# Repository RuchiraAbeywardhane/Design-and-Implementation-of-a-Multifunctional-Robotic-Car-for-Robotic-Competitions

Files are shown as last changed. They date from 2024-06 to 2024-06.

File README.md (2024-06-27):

# Agni Robot

* Agni is a robot powered by [Arduino Mega 2560](https://github.com/LasithaAmarasinghe/Agni-Robot/blob/main/Arduino%20Mega%202560%20Board.pdf), capable of doing various tasks in robotics competitions.
* This is developed for the semester 3 project under EN2533: Robot Design and Competition.
* The robot had to overcome several [tasks](https://github.com/LasithaAmarasinghe/Agni-Robot/blob/main/Robotics_Task.pdf) in this competition, which was held in an [arena](https://github.com/LasithaAmarasinghe/Agni-Robot/blob/main/Competition%20Arena.png) prepared in the ENTC building. 

IMG-20231209-WA00

## Functionalities

🛤️ Precise line following  
🚧 Wall avoidance during navigation  
🏞️ Navigating ramps (20 degrees)  
🤖 Object interaction with a mechanical arm  
🎵 Sound sensitivity   
🌈 Colour detection  
🌀 Maze-traversing capabilities  
🛑 Obstacle avoidance, including guard robots  

## Game Plan

### Task 1: Line Following
* For the initial task of the competition, the robot needs to follow the white line on the black background. To detect the line with better accuracy we used an IR array with 8 IR modules. For smoothing the movement of the robot we added a PID controller. The PID control processes the IR sensor data and makes real-time adjustments to the robot's motor output, ensuring that it stays on the line with precision.

### Task 2: Wall Following
* In this task, the white line is disturbed by walls at some points and the robot needs to follow the white line, avoiding the walls. To detect walls we used ultrasonic sensors. The robot manages to keep a constant distance from the walls in disturbed areas and comes back to the white line after that according to the algorithm.

### Task 3: Ramp Navigation
* To go through the ramp we focused on what needed to be done by the mechanical design side. We calculated the height that the chassis needs to be from the ground and where the tyres should be situated relative to the chassis. The PID controller is adjusted for this task to slow down the robot when it comes near the ramp, so the robot can smoothly enter the ramp.

### Task 4: Box Manipulation
* To tackle the box manipulation challenge, we added a robotic arm with stepper motors equipped with joints for precise movements. We used ultrasonic sensors to detect the presence of the box. After the box is detected, the arm grabs the box according to the code.

### Task 5: Coloured Line Following
* For this task, the robot needs to identify the colour of the box and follow the path with the same colour as the box. First, the box is picked up by the arm, and then using the colour sensor, the box's colour is detected. According to the colour of the box, the robot follows the line according to the right-hand rule to reach the destination.

### Task 6: Sound Detection
* In this part, there is a sound-emitting tower. The robot should freeze when a sound is emitted from the tower and should move only when it's silent. With the sound sensor, the robot detects the sound and moves according to the algorithm. 

### Task 7: Guard Bot Avoidance
* In the final task, the robot encounters a guard robot blocking its path. Ultrasound sensors are strategically positioned on the front sides of the robot to detect the movements of the guard bot. When the bot moves away from our destination, our robot successfully evades the guard robot and reaches the final destination.

## Hardware Specifications

* [Arduino Mega 2560](https://github.com/LasithaAmarasinghe/Agni-Robot/blob/main/Arduino%20Mega%202560%20Board.pdf)
* [Sensors](https://github.com/LasithaAmarasinghe/Agni-Robot/blob/main/AGNI%20sensors%20.pdf)
* Buck Converter
* 2 Li-ion Batteries
* 2 N20 50 rpm Motors
* Wheels

## Software Specifications

* Arduino IDE
* Solid Works




## Sensors



## Chassie Design

Bottom Chassie

## Team


<p align="center">
  Image Description
</p>

## License
 
 * This project is licensed under the MIT License. See the [LICENSE](MIT-LICENSE.txt) file for details.

## For More Information - [Project Report](https://github.com/LasithaAmarasinghe/Agni-Robot/blob/main/Agni%20final%20report.pdf)

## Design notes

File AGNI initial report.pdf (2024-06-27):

### EN2533 Robot Design and Competition Team AGNI Overview

Overall Strategy

Line Following:
We will use 10 analog IR sensors to detect the white colour line. These sensors provide analog values, and by setting a threshold value these values can be converted into digital values. Then the PID algorithm, which is implemented in a microcontroller, will set the speed of each motor.

Wall Following:
We will use two TOF sensors to both sides of the robot. According to their input, the distance of the obstacle will be calculated and motor speed will be changed. It is important to note that for this task we will give priority to obstacle avoidance over line following.

Bridge:
Throughout this task, the line following method will be used. If we find a small door open box, the arm will grab the box, then the robot will move backward until it reaches the junction. then it turns right and moves forward until it reaches checkpoint 4 again.

Colour line:
Firstly, to detect the colour of the box we will use an RGB colour sensor. Then we will use 10 IR sensors which are already used for line following. But for this task we will change the threshold values for red and blue. We are also going to use the PID algorithm, but here we will use a search method to reach checkpoint 6.

Mechanical Design

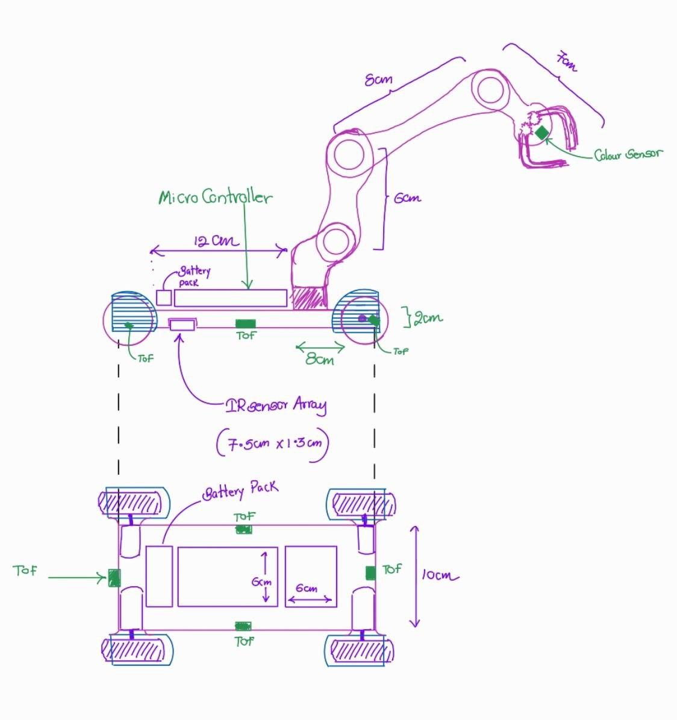
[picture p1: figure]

Sensors

Obstacle Detection & Guard Bot part: Selected Sensor: TOF VL6180V1 Proximity Sensor
Reasons for Selection:
- High accuracy in measuring distances
- Unaffected by ambient light
- Small physical size for flexible integration
- Extended range from 0 to 60cm

Line Following:
Selected Sensor: IR Array
Reasons for Selection:
- Provides wider coverage area for efficient line following
- Simplifies sensor setup with multiple IR sensors in one package

Colour Detection:
Selected Sensor: TCS230 Color Sensor Reasons for Selection:
- High accuracy in colour detection

- Versatile in distinguishing a wide range of colours

Sound Detection:
Selected Sensor: MD0220 Voice Sound Detection Mic Sensor
Reasons for Selection:
- Designed specifically for voice and sound detection
- Optimised for voice detection, suitable for reacting to voice commands or environmental
sounds

Actuators

We plan to use two N20 motors for rear wheels.
Options - N20 motors, plastic motors Reasons for Selection:
- higher efficiency
- low power consumption,
- It has the required rpm value to carry the robot on the ramp. Algorithms

Line Following
get input from IR and A2D Conversion calculate Speed using PID (Proportional integral derivative Algorithm)
set speed

Obstacle Detection
get input from TOF sensor
calculate distance (D)
if D <2cm
set new speed according the TOF sensor side

Red/Blue Line Following
get input from IR and A2D Conversion if all (IR) = 0
turn 180°
forward

until All (IR) != 0
else
calculate speed using PID [Priority Left, Forward, Right]
set speed

Box Detection
get TOF input [ Front TOF] calculate distance
forward until distance = d cm //d will be determined

Sound Detection
get input from sound sensor if input = 1
follow line
else
break

Guard Bot
get input from TOF sensors
if right TOF detects before left TOF turn right
forward
until find checkpoint 8
else
wait
Task Delegation
- Thamirawaran - Line following, obstacle avoiding
- Ruchira Abeywardane -PCB design, arm coding part.
- Lasitha Amarasinghe -Guard bot part, Adjust the overall code for task wise functioning
- Rajitha Niroshan -Solidwork design, Ramp Task
- Sahan Abeyrathna -Colour detection and sound detection part

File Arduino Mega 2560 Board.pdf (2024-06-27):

Arduino Mega 2560 Board

The Arduino Mega 2560 is a microcontroller board designed for more complex projects that require a greater number of input and output (I/O) pins, larger sketch memory, and more RAM. It’s easier to work with arduino Mega 2560 thanks to its 54 digital I/O pins, 16 analog inputs and larger space . It is a more advanced version of the traditional Arduino boards with a wide range of subsystems to enable different functionalities.

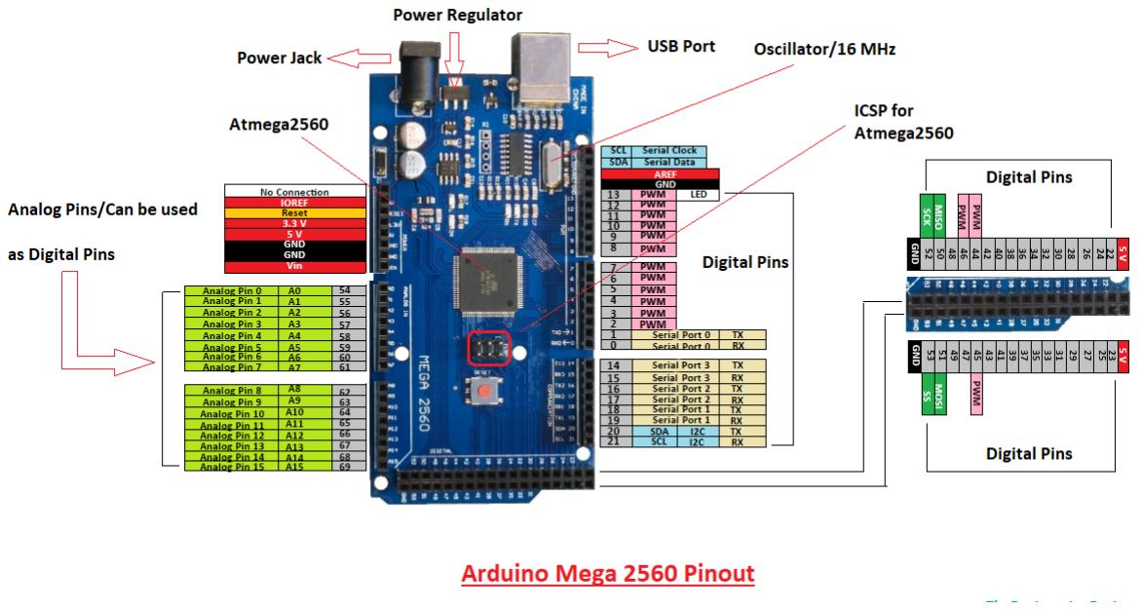
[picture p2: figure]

1. Microcontroller Unit (MCU):
- This is an 8-bit AVR microcontroller.
- The MCU is responsible for executing the programs, handling digital and analog input/output, and controlling various sensors and actuators.
- It has built-in Flash memory for program storage, SRAM for variable storage, and EEPROM for data storage.
2. 54 Digital I/O Pins:
- The Arduino Mega 2560 offers 54 digital I/O pins. These pins can be used for digital input or output operations.
- Each digital I/O pin is connected to the MCU, allowing to control external devices, such as LEDs, motors, and relays.
3. 16 Analog Input Pins:
- The board provides 16 analog input pins, which can be used to read analog signals from sensors.
- The analog-to-digital converter (ADC) subsystem within the MCU converts these analog signals into digital values for use in the sketch.

4. Crystal Oscillator:
- The MCU typically uses a crystal oscillator to provides exceptional frequency accuracy and stability.
- The Arduino Mega 2560 uses a 16 MHz crystal oscillator.
5. Voltage Regulator:
- This provides a stable 5V supply from the external power source (usually 7-12V DC).
- This ensures that the MCU and other components receive a consistent and regulated voltage.
6. USB Interface:
- USB-to-Serial converter allows to connect the Arduino to a computer for programming and communication.
- It also powers the board and can be used for serial communication between the board and the computer.
7. Power Supply Connectors:
- There are multiple power supply connectors, such as the barrel jack and Vin pin, for providing power to the board from external sources.
- Can choose between the USB power source and an external power supply, depending on application.
8. Reset Button:
- This allows to reset the microcontroller, which is useful for restarting the sketch or entering the bootloader for programming.
9. Communication Interfaces:
- Arduino Mega 2560 has multiple communication interfaces, including UART (Serial), SPI, and I2C, which allow to communicate with other devices and sensors.
10. LEDs:
- LEDs are often used for debugging and status monitoring.

These subsystems and components work together to make the Arduino Mega 2560 a versatile and powerful development platform for a wide range of projects.

Resourceshttps://store.arduino.cc/products/arduino-mega-2560-rev3https://www.theengineeringprojects.com/2018/06/introduction-to-arduino-mega -2560.html (https://www.theengineeringprojects.com/2018/06/introduction-to-arduino-mega-2560.html)

Lasitha Amarasinghe - 210031H - Agni

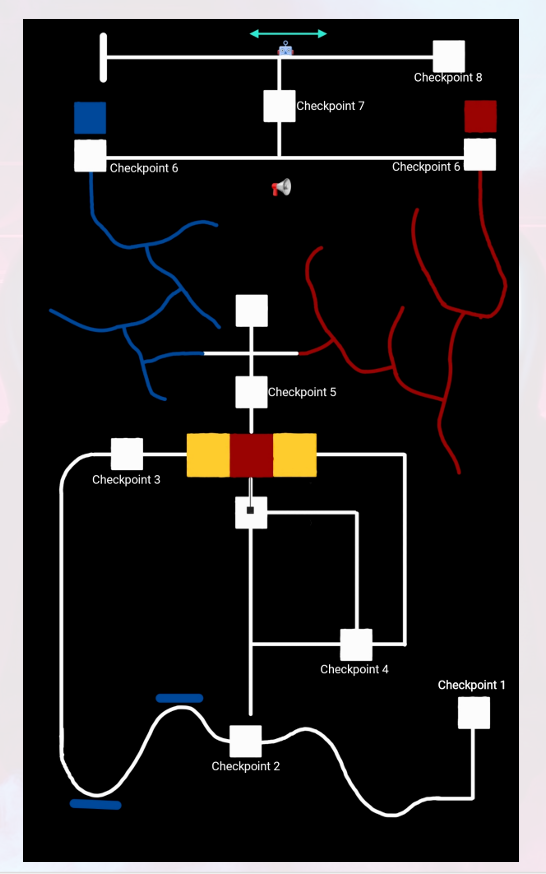
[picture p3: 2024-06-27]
Competition Arena.png

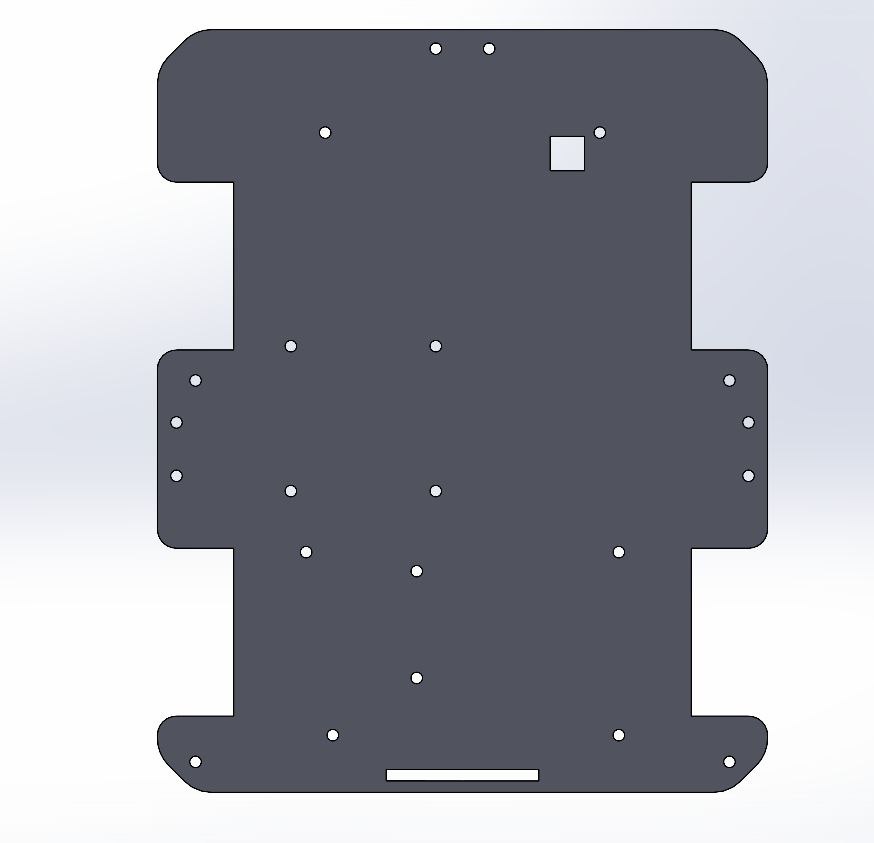
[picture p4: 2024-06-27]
Solid works/bottom chassie.jpg

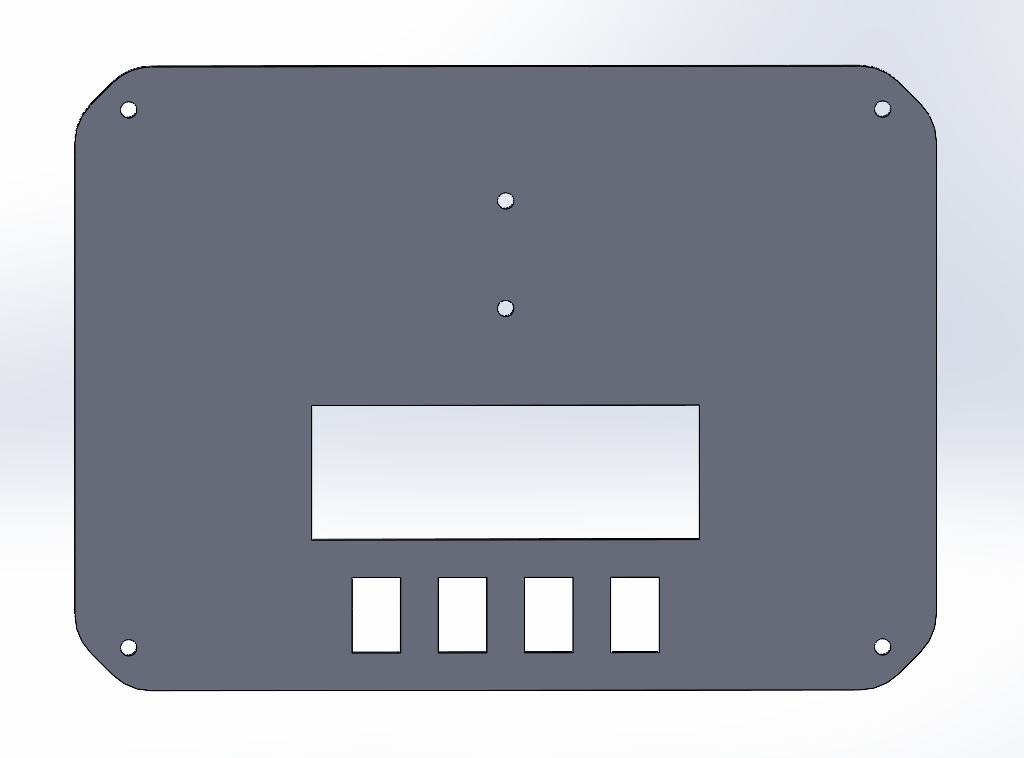
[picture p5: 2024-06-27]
Solid works/top chassie.jpg

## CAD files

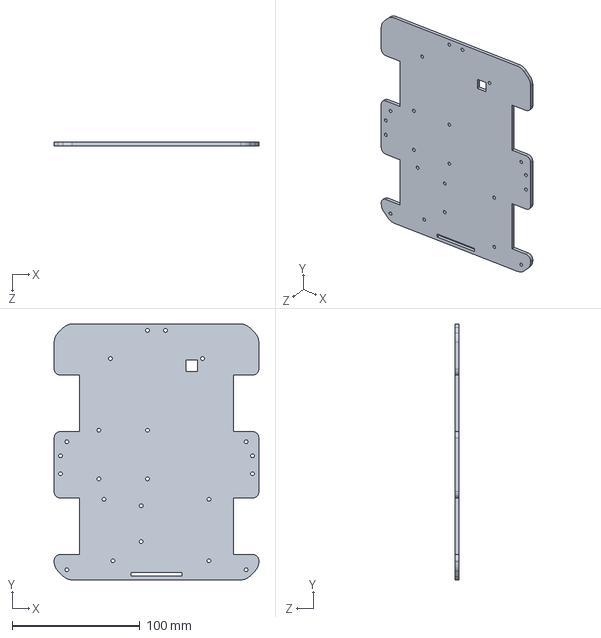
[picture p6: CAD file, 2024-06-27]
Solid works/chassie_1.SLDPRT
160.0 x 200.0 x 3.00 mm

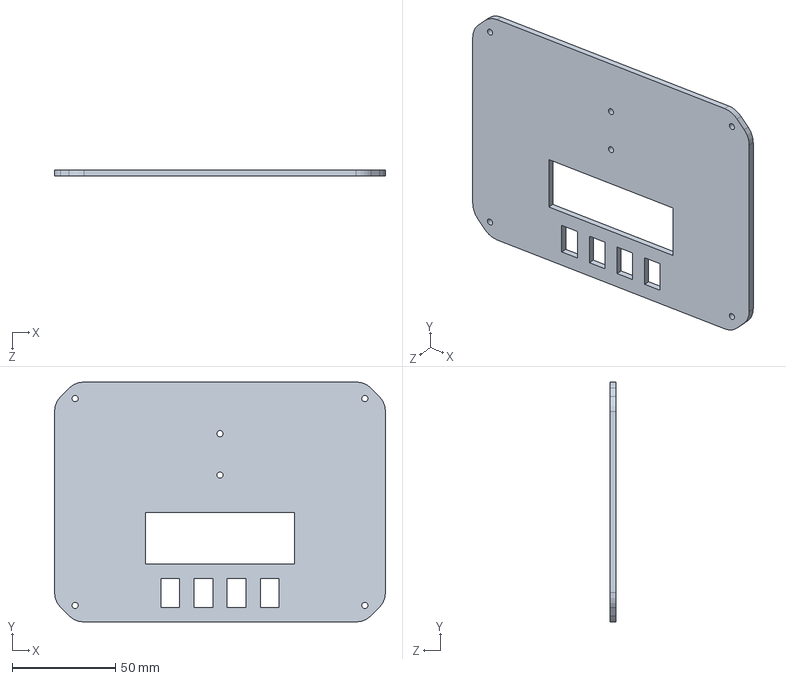
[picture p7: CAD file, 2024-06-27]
Solid works/chassie_2.SLDPRT
160.0 x 116.0 x 3.00 mm

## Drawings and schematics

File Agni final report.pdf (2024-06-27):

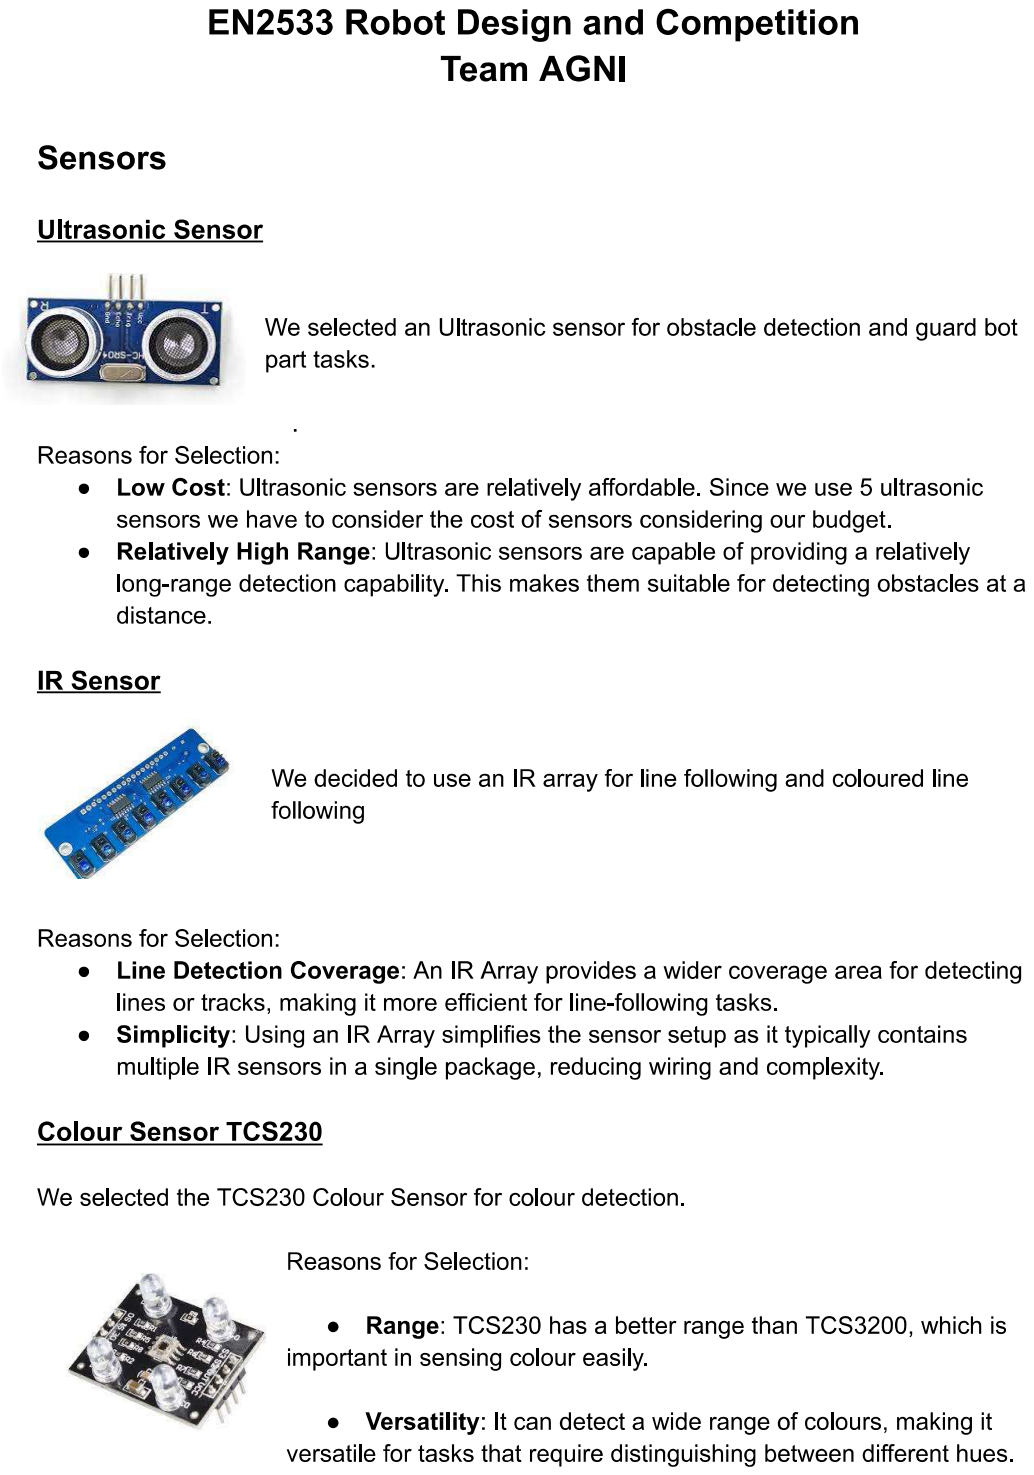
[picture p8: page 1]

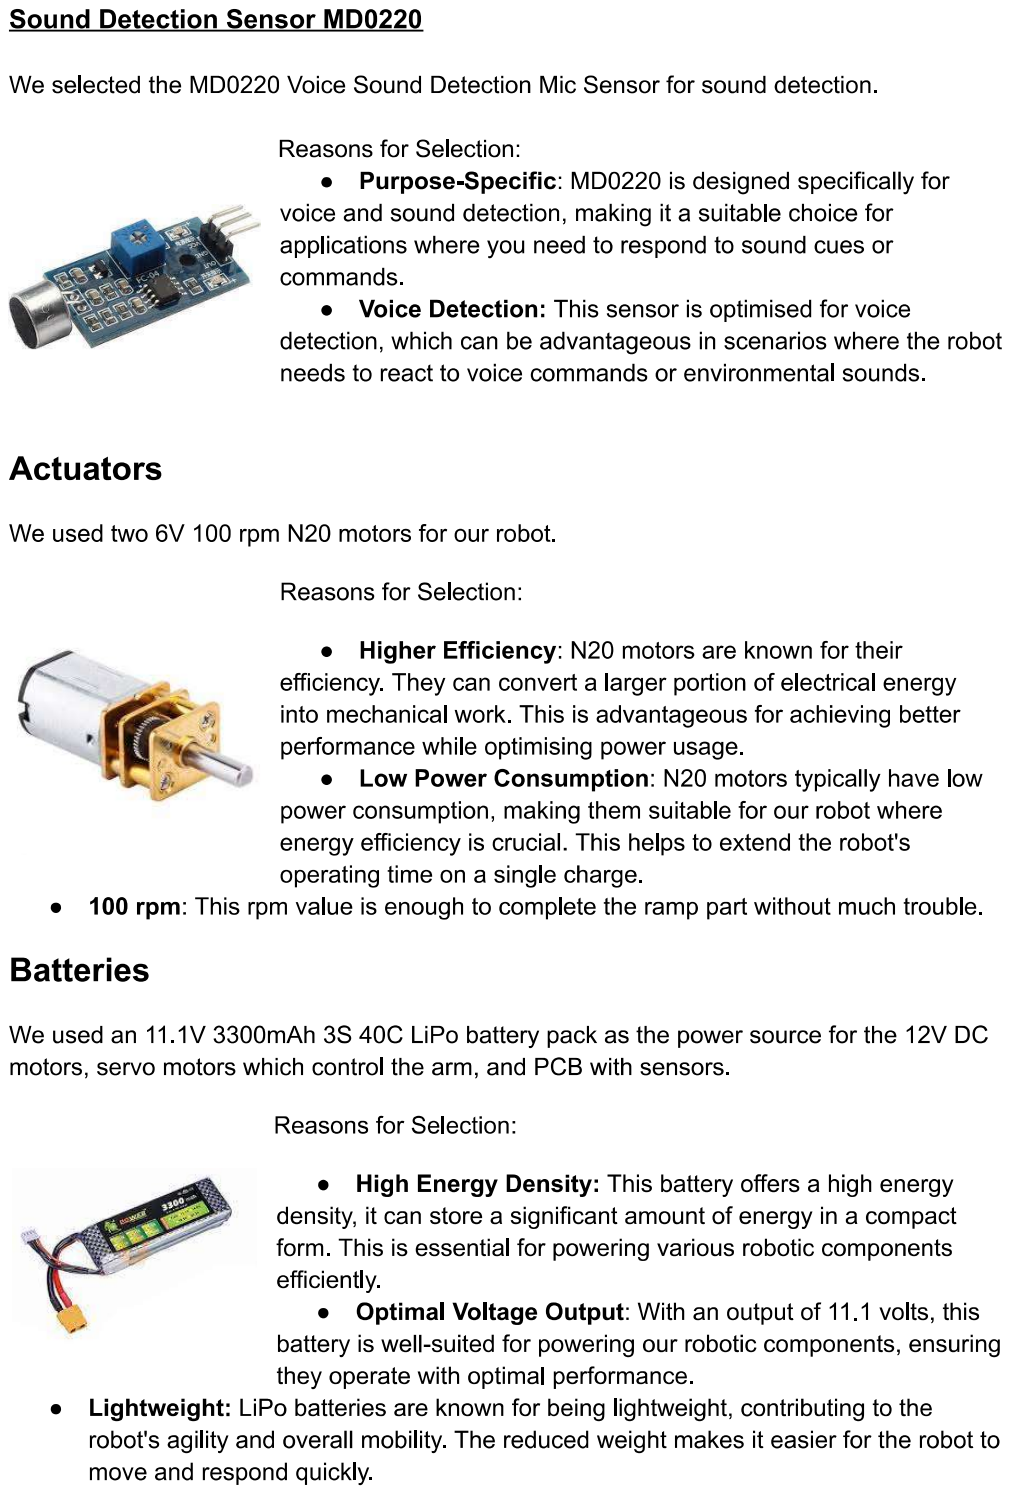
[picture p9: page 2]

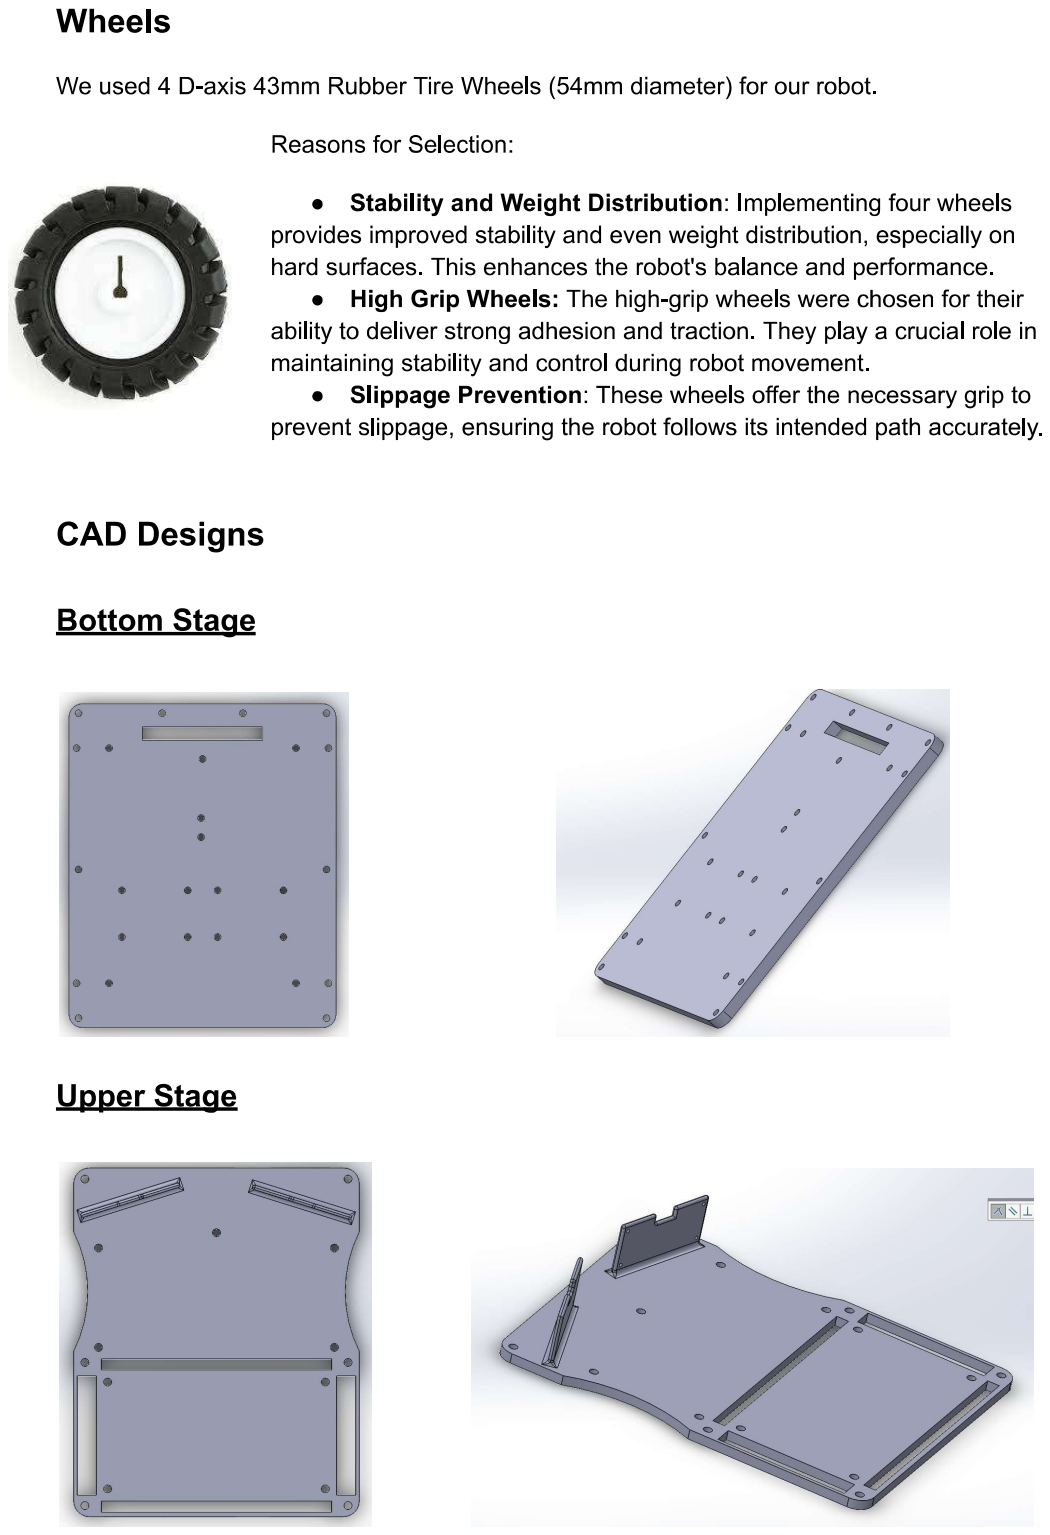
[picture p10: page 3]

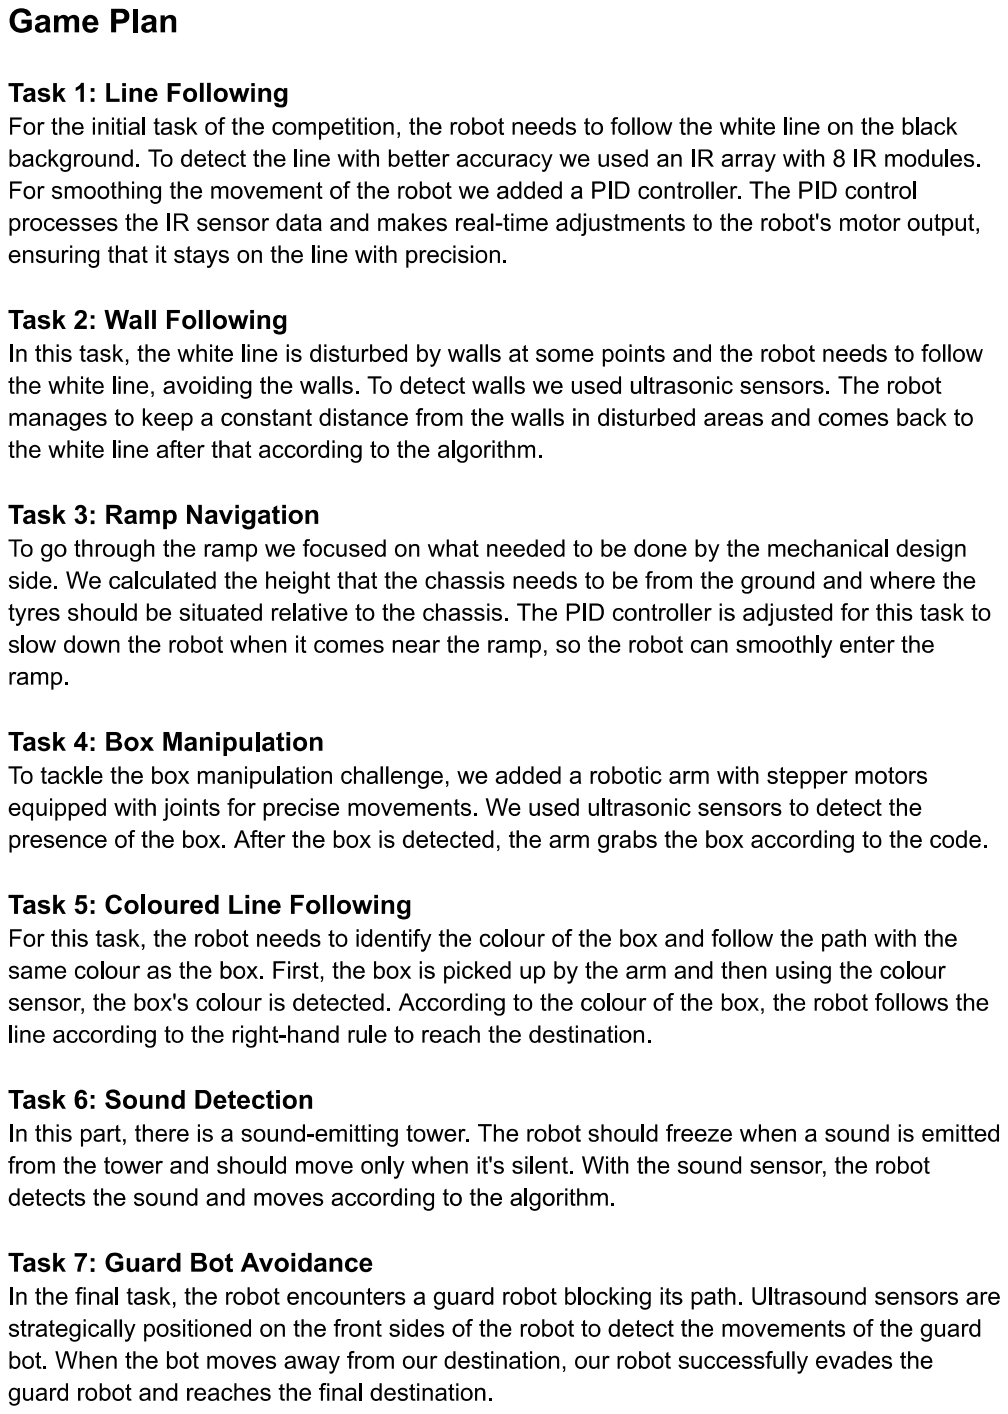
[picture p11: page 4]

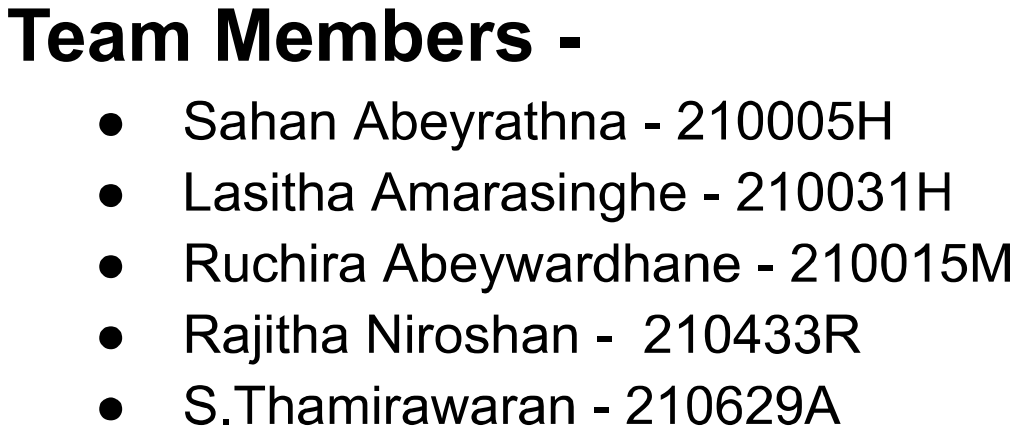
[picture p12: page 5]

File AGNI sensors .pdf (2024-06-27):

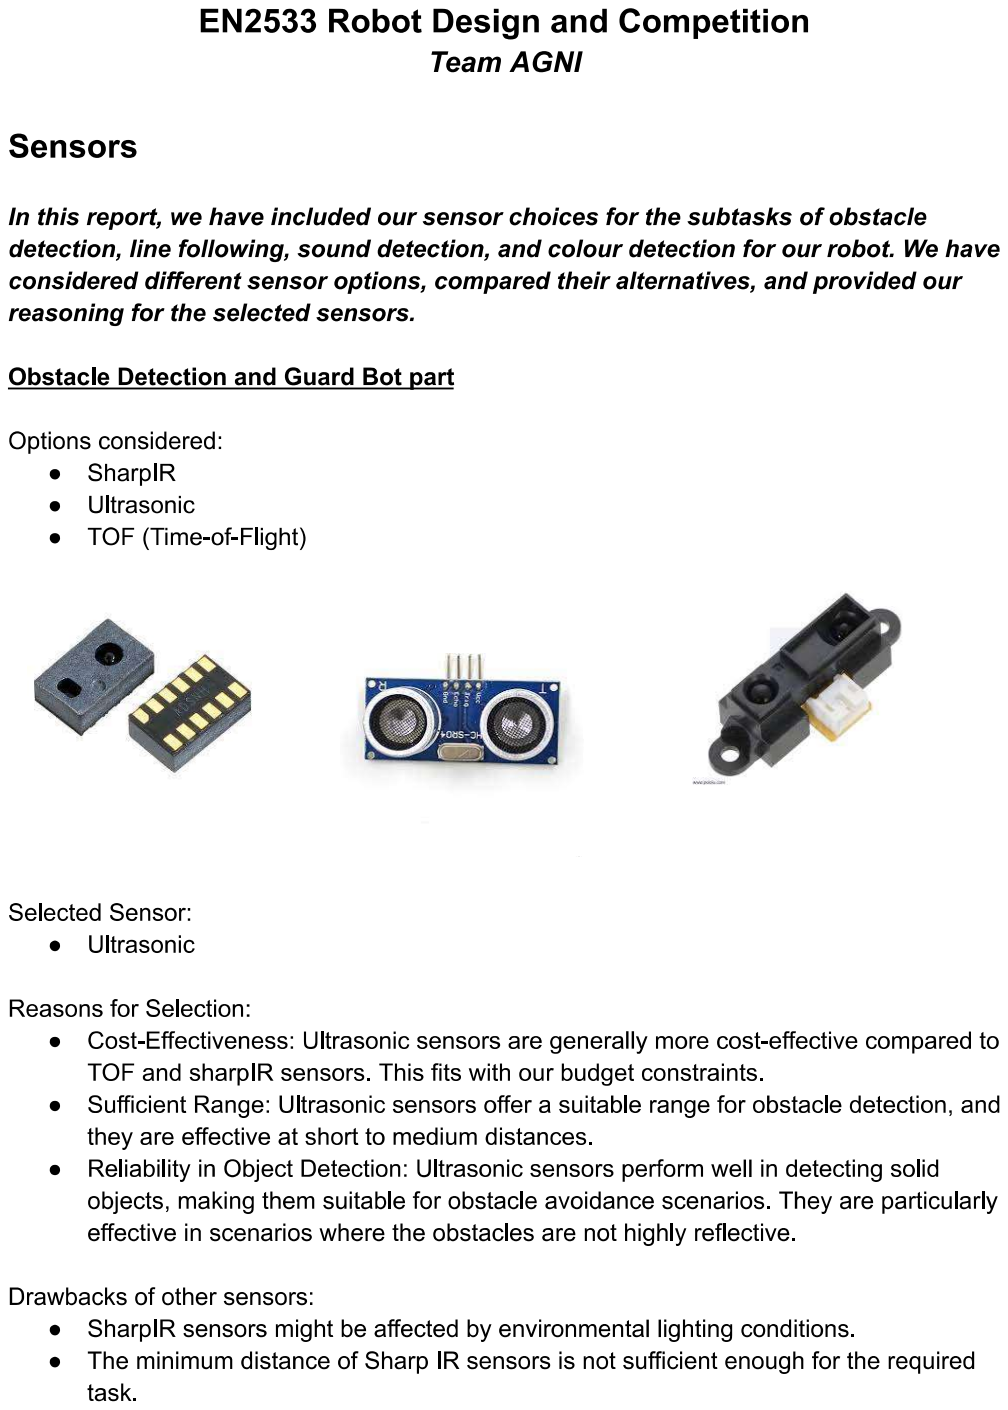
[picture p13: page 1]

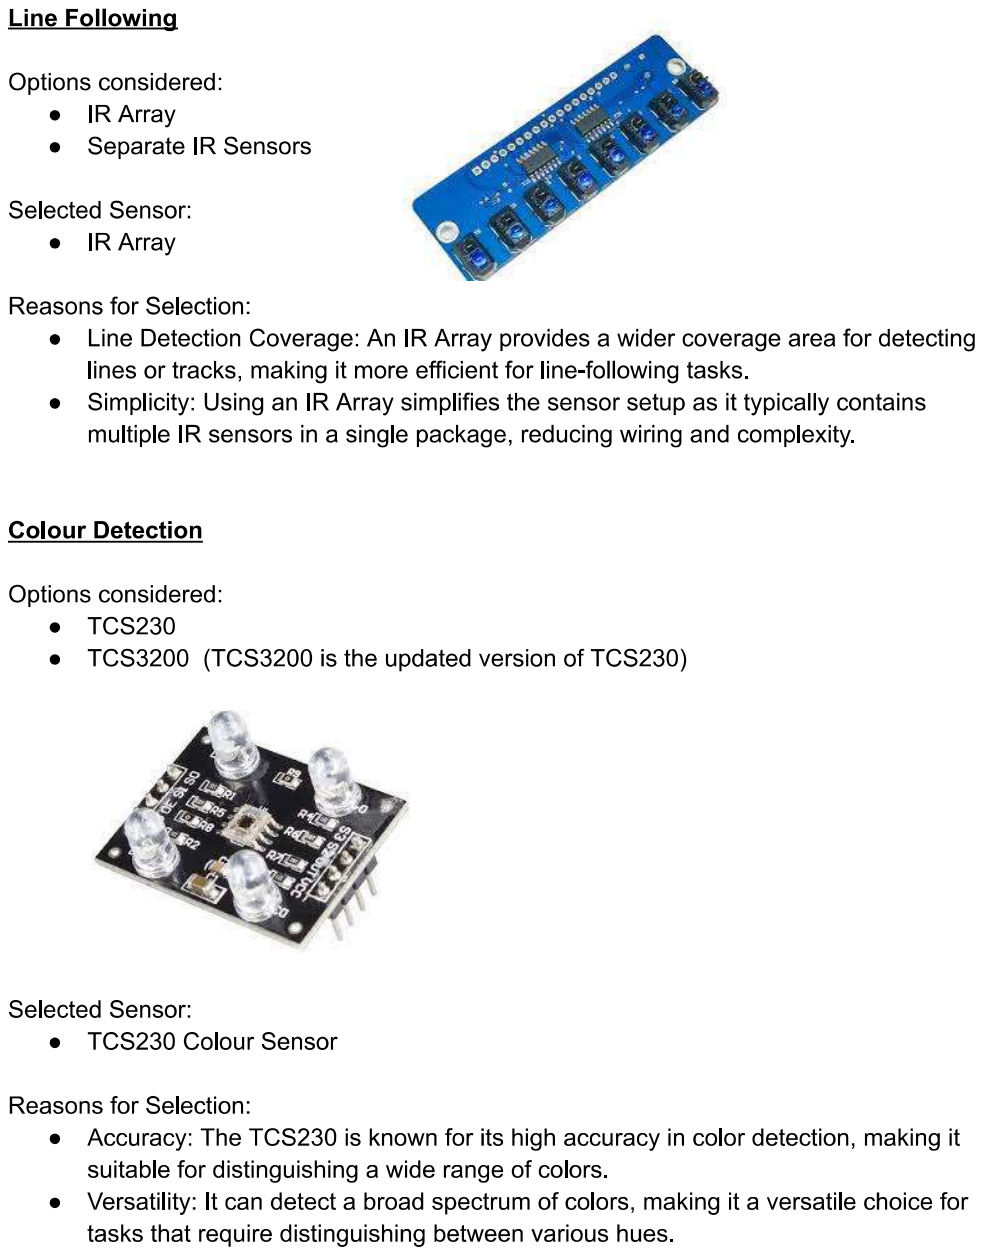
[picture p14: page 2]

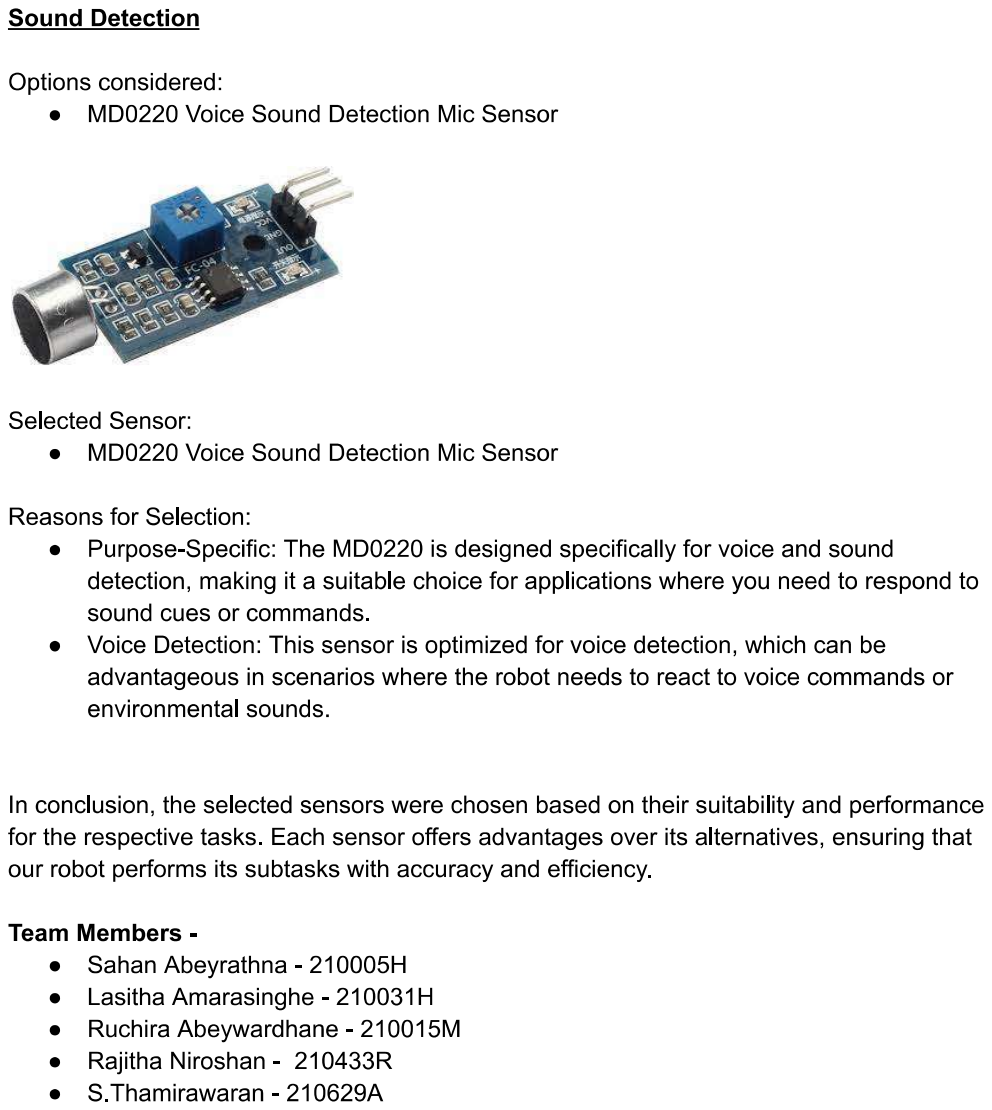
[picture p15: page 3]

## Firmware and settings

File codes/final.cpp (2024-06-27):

#include <Arduino.h>
#include <Wire.h>
#include <Servo.h>
#include <NewPing.h>


#define IR1 A0
#define IR2 A1
#define IR3 A2
#define IR4 A3
#define IR5 A4
#define IR6 A5
#define IR7 A6
#define IR8 A7

#define RMotorA 4
#define RMotorB 2
#define RMotorPWM 3

#define LMotorA 7
#define LMotorB 6
#define LMotorPWM 5

#define S0 A9
#define S1 A10
#define S2 A15
#define S3 A14
#define sensorOut A12
#define colourVcc A13
#define colourGnd A11

#define sensor A14 // Sharp IR GP2Y0A41SK0F (4-30cm, analog)

#define HighSwitch 36
#define RightSwitch 34
#define MiddleSwitch 32
#define LeftSwitch 30

#define MAX_DISTANCE 20 // Maximum distance we want to ping for (in centimeters). Maximum sensor distance is rated at 400-500cm.


// Stores frequency read by the photodiodes
int red = 0;
int green = 0;
int blue = 0;


// Define pins for the  sensor-Front left sensor
const int trigPin_FL = 45;
const int echoPin_FL = 47;
const int gndPin_FL = 49;

// Define pins for the sensor-left
const int trigPin_L = 51;
const int echoPin_L = 53;

// Define pins for the third sensor-middle sensor
const int trigPin_M = 39;
const int echoPin_M = 41;
const int gndPin_M = 43;


// Define pins for the fourth sensor-right  sensor
const int trigPin_R = 36;
const int echoPin_R = 38;
const int gndPin_R = 40;

// Define pins for the fifth sensor-right front sensor
const int trigPin_FR = 46;
const int echoPin_FR = 48;
const int gndPin_FR = 52;


//Ground sharpir
const int sharpGND = 22;

// Declare the Servo pin
int servoPin1 = 9;
int servoPin2 = 8;

// Declare distances to walls
int ultradist = 0;
int ultradist1 = 0;
int ultradist2 = 0;
int ultradist3 = 0;
int ultradist4 = 0;
int ultradist5 = 0;

int start = 0;

int BaseSpeed = 80;
int MinSpeed = 0;
int MaxSpeed = 160;

int IR_D_val[8] = {0, 0, 0, 0, 0, 0, 0, 0};
int Temp_IR_D_val[8];
int IR_A_val[8] = {0, 0, 0, 0, 0, 0, 0, 0};
//int IR_Weight[8]= {-20, -10, -5, 0 , 0 , 5, 10, 20};
int IR_Weight[8] = { -35, -20, -10, -5 , 5 , 10, 20, 35};

int LMotorSpeed = 0;
int RMotorSpeed = 0;
int SpeedAdjust = 0;

float P, I, D;
float Error = 0;
float PreviousError = 0;
float Kp = 10; //2.8
float Kd = 0;
float Ki = 0;

void PID_control();
void read_IR();
void set_speed();
void set_forward();

//Calibeartion Arrays
const int Buzzer = 51;
const int BuzzerGND = 44;
int caliberation_threshold[8];

// Create a servo object
Servo Servo1; //servo which controls rotation of arm
Servo Servo2; //servo which controls gripper part

int stage = 2;

const int soundSensorPin = A1;

void setup() {
  Serial.begin(9600);


  // Setting colour sensor outputs
  pinMode(S0, OUTPUT);
  pinMode(S1, OUTPUT);
  pinMode(S2, OUTPUT);
  pinMode(S3, OUTPUT);
  pinMode(sensorOut, INPUT);  // Setting the sensorOut as an input
  digitalWrite(S0, HIGH);     // Setting frequency scaling to 20%
  digitalWrite(S1, LOW);
  digitalWrite(colourVcc, HIGH);
  digitalWrite(colourGnd, LOW);

  // Set up pins for ultrasonic sensors
  pinMode(trigPin_FL, OUTPUT);
  pinMode(echoPin_FL, INPUT);
  pinMode(trigPin_L, OUTPUT);
  pinMode(echoPin_L, INPUT);
  pinMode(trigPin_M, OUTPUT);
  pinMode(echoPin_M, INPUT);
  pinMode(trigPin_R, OUTPUT);
  pinMode(echoPin_R, INPUT);
  pinMode(trigPin_FR, OUTPUT);
  pinMode(echoPin_FR, INPUT);

  //sharpir pins
  pinMode(sharpGND, OUTPUT);
  pinMode(sharpIR, INPUT);
  digitalWrite(sharpGND, LOW);


  //Defining Pin modes for the Buzzer(Caliberation)
  pinMode(Buzzer, OUTPUT);
  pinMode(BuzzerGND, OUTPUT);
  digitalWrite(Buzzer, LOW);
  digitalWrite(Buzzer, LOW);

  pinMode(IR1, INPUT);
  pinMode(IR2, INPUT);
  pinMode(IR3, INPUT);
  pinMode(IR4, INPUT);
  pinMode(IR5, INPUT);
  pinMode(IR6, INPUT);
  pinMode(IR7, INPUT);
  pinMode(IR8, INPUT);

  pinMode(RMotorA, OUTPUT);
  pinMode(RMotorB, OUTPUT);
  pinMode(RMotorPWM, OUTPUT);

  pinMode(LMotorA, OUTPUT);
  pinMode(LMotorB, OUTPUT);
  pinMode(LMotorPWM, OUTPUT);

  Servo1.attach(servoPin1);
  Servo2.attach(servoPin2);

  set_forward();
  Servo1.write(70);
  Servo2.write(90);
  delay(500);


//ultrasonic grounds
  digitalWrite(gndPin_FR, LOW);
  //  digitalWrite(gndPin2, LOW);
  digitalWrite(gndPin_R, LOW);
  digitalWrite(gndPin_M, LOW);
  digitalWrite(gndPin_FL, LOW);

}

/////////////////Direction///////////////////////////
int turnTo(int dataset[]) { //Determine where to turn to lose the deviation
  int sumRight = 0;
  int sumLeft = 0;
  for (int i = 0; i < 4; i++) {
    sumRight += dataset[i];
    sumLeft += dataset[i + 4];
  }
  if (sumRight > sumLeft) {
    return 1; //1 means turn right, if the vehicle is turning wrong change this to 0
  }
  else {
    return 0; //0 means Turn Left
  }
}
//////////////////////////////////////////////////////


/////////////////Deviator///////////////////////////
int deviator(int dataset[]) { ///Check if the robot has deviated from the line
  if (dataset[0] == 1 && dataset[1] == 1 && dataset[2] == 1 && dataset[3] == 1 && dataset[4] == 1 && dataset[5] == 1 && dataset[6] == 1 && dataset[7] == 1 ) {
    return 1;
  }
  else {
    return 0;
  }
}
//////////////////////////////////////////////////////


/////////////////Checkpoint///////////////////////////
int checkpoint(int dataset[]) { ///Check if the robot has reached a checkpoint
  if (dataset[0] == 0 && dataset[1] == 0 && dataset[2] == 0 && dataset[3] == 0 && dataset[4] == 0 && dataset[5] == 0 && dataset[6] == 0 && dataset[7] == 0 ) {
    return 1;
  }
  else {
    return 0;
  }
}
//////////////////////////////////////////////////////
void PID_control() {
  Error = 0;
  for (int i = 0; i < 8; i++) {
    Error += IR_Weight[i] * IR_D_val[i];
  }
  P = Error;
  I = I + Error;
  D = Error - PreviousError;
  PreviousError = Error;

  SpeedAdjust = (Kp * P + Ki * I + Kd * D);

  LMotorSpeed = BaseSpeed - SpeedAdjust;
  RMotorSpeed = BaseSpeed + SpeedAdjust;
  // delay(5000);

  if (LMotorSpeed < 0 ) {
    LMotorSpeed = 0;
  }
  if (RMotorSpeed < 0) {
    RMotorSpeed = 0;
  }
  if (LMotorSpeed > MaxSpeed) {
    LMotorSpeed = MaxSpeed;
  }
  if (RMotorSpeed > MaxSpeed) {
    RMotorSpeed = MaxSpeed;
  }

}
void stage5(){
  /*if (ultradist1<8){
    stop();
  }*/
    //Colour sensor 
    
    // Setting RED (R) filtered photodiodes to be read
    digitalWrite(S2,LOW);
    digitalWrite(S3,LOW);
    red = pulseIn(sensorOut, LOW);
    Serial.println("R:");
    Serial.println(red);
    
    // Setting GREEN (G) filtered photodiodes to be read
    digitalWrite(S2,HIGH);
    digitalWrite(S3,HIGH);
    green = pulseIn(sensorOut, LOW);
    Serial.println("G:");
    Serial.println(green);
    
    // Setting BLUE (B) filtered photodiodes to be read
    digitalWrite(S2,LOW);
    digitalWrite(S3,HIGH);
    blue = pulseIn(sensorOut, LOW);
    Serial.println("B:");
    Serial.println(blue);
    
    if (red>blue){
      Serial.println('red');
      }
    else if (red<blue){
      Serial.println('blue');
    }        
  }
void read_IR() {
  IR_A_val[0] = analogRead(IR1);
  IR_A_val[1] = analogRead(IR2);
  IR_A_val[2] = analogRead(IR3);
  IR_A_val[3] = analogRead(IR4);
  IR_A_val[4] = analogRead(IR5);
  IR_A_val[5] = analogRead(IR6);
  IR_A_val[6] = analogRead(IR7);
  IR_A_val[7] = analogRead(IR8);

  for (int i = 0; i < 8; i++)
  {
    if (IR_A_val[i] <= 300) {  //IR_A_val[i] >= caliberation_threshold[i] For Black Line
      IR_D_val[i] = 0;
    }
    else if (IR_A_val[i] >= 300) {
      IR_D_val[i] = 1;
    }
  }
}


void set_speed() {
  analogWrite(LMotorPWM, LMotorSpeed);
  analogWrite(RMotorPWM, RMotorSpeed);
}

void set_forward() {
  digitalWrite(LMotorB, HIGH);
  digitalWrite(LMotorA, LOW);
  digitalWrite(RMotorB, HIGH);
  digitalWrite(RMotorA, LOW);
}

void TurnRight() {
  analogWrite(LMotorPWM, 100);
  analogWrite(RMotorPWM, 100);
  digitalWrite(LMotorB, HIGH);
  digitalWrite(LMotorA, LOW);
  digitalWrite(RMotorB, LOW);
  digitalWrite(RMotorA, HIGH);
}


void TurnLeft() {
  analogWrite(LMotorPWM, 100);
  analogWrite(RMotorPWM, 100);
  digitalWrite(LMotorB, LOW);
  digitalWrite(LMotorA, HIGH);
  digitalWrite(RMotorB, HIGH);
  digitalWrite(RMotorA, LOW);
}

void stop() {
  digitalWrite(LMotorB, LOW);
  digitalWrite(LMotorA, LOW);
  digitalWrite(RMotorB, LOW);
  digitalWrite(RMotorA, LOW);
}


/////////////////////Caliberation//////////////////////
void caliberation() {
  int caliberation_data[8][12] = {
    {}, // Inner array 1
    {}, // Inner array 2
    {}, // Inner array 3
    {}, // Inner array 4
    {}, // Inner array 5
    {}, // Inner array 6
    {}, // Inner array 7
    {}  // Inner array 8
  };
  delay(2000);
  digitalWrite(Buzzer, HIGH);
  delay(100);
  digitalWrite(Buzzer, LOW);
  delay(3000);

  int n = 0;
  for (int i = 0; i < 12; i++) {
    Serial.println(n);
    for (int j = 0; j < 8; j++) {
      caliberation_data[j][i] = analogRead(IR_A_val[j]); //j value represents the IR single modules i represents the number of times values are taken
    }
    if (n == 2) {
      //Go forward few steps
      analogWrite(LMotorPWM, 255);
      analogWrite(RMotorPWM, 255);
      set_forward();
      delay(500);
      stop();
    }
    else if (n == 5) {
      //Double beep to notify to move the car
      digitalWrite(Buzzer, HIGH);
      delay(100);
      digitalWrite(Buzzer, LOW);
      delay(100);
      digitalWrite(Buzzer, HIGH);
      delay(100);
      digitalWrite(Buzzer, LOW);
      delay(4000);
    }
    else if (n == 8) {
      //Go forward few steps
      analogWrite(LMotorPWM, 255);
      analogWrite(RMotorPWM, 255);
      set_forward();
      delay(500);
      stop();
    }
    else if (n == 11) {
      digitalWrite(Buzzer, HIGH);
      delay(100);
      digitalWrite(Buzzer, LOW);
      delay(100);
      digitalWrite(Buzzer, HIGH);
      delay(100);
      digitalWrite(Buzzer, LOW);
      delay(100);
      digitalWrite(Buzzer, HIGH);
      delay(100);
      digitalWrite(Buzzer, LOW);
      delay(4000);
      //End
    }
    n = n + 1;
  }

  for (int j = 0; j < 8 ; j++) {
    int maxi = 0;
    int mini = 0;
    for (int i = 0; i < 12; i++) {
      if (caliberation_data[j][i] > maxi) {
        maxi = caliberation_data[j][i];
      }
      else if (caliberation_data[j][i] < mini) {
        mini = caliberation_data[j][i];
      }
    }
    int avg = (maxi + mini) / 2;
    caliberation_threshold[j] = avg;
  }
}
///////////////////////////////////////////////////////
///////////////////GetBackTothePath///////////////////
void getBackPath(int hasDeviate) {
  //direction
  int turningTo = turnTo(Temp_IR_D_val);
  if (turningTo == 0) {
    ////turnleft
    ///when black detected
    delay(250);
    while (hasDeviate == 1) {
      TurnLeft();
      read_IR();
      hasDeviate = deviator(IR_D_val);
    }

  }
  else {
    //turn right
    ///when black detected
    delay(250);
    while (hasDeviate == 1) {
      TurnRight();
      read_IR();
      hasDeviate = deviator(IR_D_val);
    }

  }
}

/////////////////GetDistance///////////////////////
float getDistance(int trigPin, int echoPin) {
  NewPing sonar(trigPin, echoPin, MAX_DISTANCE); // NewPing setup of pins and maximum distance.
  float distance;
  delay(50);
  distance = sonar.ping_cm(); // Wait 50ms between pings (about 20 pings/sec). 29ms should be the shortest delay between pings.
  return distance;
}

////////////////////////////////////////////////////
////////////////////LineFollow//////////////////////
void LineFollow() {
  set_forward();
  PID_control();
  set_speed();
  for (int i = 0; i < 8; i++) {
    Temp_IR_D_val[i] = IR_D_val[i];
  }
}
/////////////////////////////////////////
/////////////////sharpIR////////////////
// 5v
float sharpIR() {
  float volts = analogRead(sensor) * 0.0048828125; // value from sensor * (5/1024)
  int distance = 13 * pow(volts, -1); // worked out from datasheet graph
  delay(10); // slow down serial port

  if (distance <= 30) {
    Serial.println(distance);   // print the distance
  }
}
//////////////////////////

void loop() {
  //////Caliberate at the start
  //if (start == 0) {
  //  caliberation();
  //  start += 1;
  //}
  read_IR(); //Read from IR sensor Array
  stage5();


////Detect Checkpoints///
  if (checkpoint(IR_D_val)) {
    delay(200);
    //read_IR();
    stop();
  }
  else { //Car is not at a checkpoint


    if (stage == 1) {
      Serial.println("Stage01");
      int hasDeviate = deviator(IR_D_val);
      if (hasDeviate == 1) {
        getBackPath(hasDeviate);
      }///////End of Has Deviate If statement
      else {
        LineFollow();
      }
    }//////End of Stage01



    else if (stage == 2) {
      /////Stage02
      LineFollow();
      Serial.println("*************************");
      Serial.print("front left");
      Serial.println(getDistance(trigPin_FL, echoPin_FL));
      Serial.print("left");
      Serial.println(getDistance(trigPin_L, echoPin_L));
      Serial.print("mid");
      Serial.println(getDistance(trigPin_M, echoPin_M));
      Serial.print("right");
      Serial.println(getDistance(trigPin_R, echoPin_R));
      Serial.print("front right");
      sharpIR();
      Serial.println("*************************");
      delay(2000);
    }
  }
}

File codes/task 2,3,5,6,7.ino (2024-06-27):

#include <Arduino.h>
#include <Wire.h>
#include <Adafruit_TCS34725.h>

const int IR_array[] = {A0, A1, A2, A3, A4, A5, A6, A7};  //A0-RightMost
Adafruit_TCS34725 tcs = Adafruit_TCS34725(TCS34725_INTEGRATIONTIME_50MS, TCS34725_GAIN_4X);


// Define pins for the first sensor
const int trigPin1 = 2;
const int echoPin1 = 3;

// Define pins for the second sensor
const int trigPin2 = 4;
const int echoPin2 = 5;

// Define pins for the third sensor
const int trigPin3 = 6;
const int echoPin3 = 7;

// Define pins for the fourth sensor
const int trigPin4 = 8;
const int echoPin4 = 9;

// Define pins for the fifth sensor
const int trigPin5 = 10;
const int echoPin5 = 11;

// Define motor control pins
const int leftMotorPWM = 22;   // PWM pin for speed control
const int leftMotorDir1 = 23;  // Digital pin for direction control 1
const int leftMotorDir2 = 24;  // Digital pin for direction control 2

const int rightMotorPWM = 25;  // PWM pin for speed control
const int rightMotorDir1 = 26; // Digital pin for direction control 1
const int rightMotorDir2 = 27; // Digital pin for direction control 2

// Analog input pin for the sound sensor
const int soundSensorPin = A0;  

int ultradist1 = 0;
int ultradist2 = 0;
int ultradist3 = 0;
int ultradist4 = 0;
int ultradist5 = 0;

int getDistance(int trigPin, int echoPin) {
  // Generate a pulse to trigger the sensor
  digitalWrite(trigPin, LOW);
  delayMicroseconds(2);
  digitalWrite(trigPin, HIGH);
  delayMicroseconds(10);
  digitalWrite(trigPin, LOW);

  // Measure the duration of the echo pulse
  duration = pulseIn(echoPin, HIGH);

  // Calculate and return the distance in centimeters
  return duration * 0.034 / 2;
}

void moveForward() {
  // Set motor directions to move forward
  digitalWrite(leftMotorDir1, HIGH);
  digitalWrite(leftMotorDir2, LOW);
  digitalWrite(rightMotorDir1, HIGH);
  digitalWrite(rightMotorDir2, LOW);

  // Set motor speeds
  analogWrite(leftMotorPWM, 255);  // Adjust the speed as needed
  analogWrite(rightMotorPWM, 255); // Adjust the speed as needed
}

void moveBackward() {
  // Set motor directions to move backward
  digitalWrite(leftMotorDir1, LOW);
  digitalWrite(leftMotorDir2, HIGH);
  digitalWrite(rightMotorDir1, LOW);
  digitalWrite(rightMotorDir2, HIGH);

  // Set motor speeds
  analogWrite(leftMotorPWM, 255);  // Adjust the speed as needed
  analogWrite(rightMotorPWM, 255); // Adjust the speed as needed
}

void stopRobot() {
  // Set motor directions to stop
  digitalWrite(leftMotorDir1, LOW);
  digitalWrite(leftMotorDir2, LOW);
  digitalWrite(rightMotorDir1, LOW);
  digitalWrite(rightMotorDir2, LOW);

  // Stop the motors
  analogWrite(leftMotorPWM, 0);
  analogWrite(rightMotorPWM, 0);
}

void turnright(Digitalized_Sensor_Values[3],Digitalized_Sensor_Values[4]){
  int leftSpeed=0;
  int rightSpeed=0;
  delay(500);

  while (Digitalized_Sensor_Values[3]!=1 && Digitalized_Sensor_Values[4]!=1){
  int leftSpeed = +60 ;
  int rightSpeed = -60 ;
  delay(500);
  }
}

void turnleft(Digitalized_Sensor_Values[3],Digitalized_Sensor_Values[4]){
  int leftSpeed=0;
  int rightSpeed=0;
  delay(500);

  while (Digitalized_Sensor_Values[3]!=1 && Digitalized_Sensor_Values[4]!=1){
  int leftSpeed = -60 ;
  int rightSpeed = +60 ;
  delay(500);
  }
}

void turn180(){
  int leftSpeed=0;
  int rightSpeed=0;
  delay(500);
  }

  while (Digitalized_Sensor_Values[3]!=1 && Digitalized_Sensor_Values[4]!=1){
  int leftSpeed = -60 ;
  int rightSpeed = +60 ;
  delay(500);
  }
}

void setup() {
  Serial.begin(9600); // Initialize serial communication

  // Set up pins for ultrasonic sensors
  pinMode(trigPin1, OUTPUT);
  pinMode(echoPin1, INPUT);
  pinMode(trigPin2, OUTPUT);
  pinMode(echoPin2, INPUT);
  pinMode(trigPin3, OUTPUT);
  pinMode(echoPin3, INPUT);
  pinMode(trigPin4, OUTPUT);
  pinMode(echoPin4, INPUT);
  pinMode(trigPin5, OUTPUT);
  pinMode(echoPin5, INPUT);

  // Defining pinMode of motor control pins
  pinMode(leftMotorPWM, OUTPUT);
  pinMode(leftMotorDir1, OUTPUT);
  pinMode(leftMotorDir2, OUTPUT);
  pinMode(rightMotorPWM, OUTPUT);
  pinMode(rightMotorDir1, OUTPUT);
  pinMode(rightMotorDir2, OUTPUT);
}

void loop() {
  // Measure distance for the first sensor
  ultradist1 = getDistance(trigPin1, echoPin1);

  // Measure distance for the second sensor
  ultradist2 = getDistance(trigPin2, echoPin2);

  // Measure distance for the third sensor
  ultradist3 = getDistance(trigPin3, echoPin3);

  // Measure distance for the fourth sensor
  ultradist4 = getDistance(trigPin4, echoPin4);

  // Measure distance for the fifth sensor
  ultradist5 = getDistance(trigPin5, echoPin5);

  delay(1000); // Wait for a second before the next set of measurements

  ////checkpoint2////

  ultradist= min(min(min(min(ultradist1,ultradist2),ultradist3),ultradist4),ultradist5);
  if (ultradist<700){
    stage=2;
    pidout=pidcontrol(ultradist-500);
    if (digitalizedSensorValues[3]==0||digitalizedSensorValues[4]==0){
      stage=1;
      }
    }

   ////checkpoint3////

    BaseSpeed=50;
   
   ////checkpoint5////
  
  if (ultradist1<200){
    moveForward();
    }
  Serial.println("Color sensor initialized.");
  uint16_t red, green, blue, clear;
  tcs.getRawData(&red, &green, &blue, &clear);
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
